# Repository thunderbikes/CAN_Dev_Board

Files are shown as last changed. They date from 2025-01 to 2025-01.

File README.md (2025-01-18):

# Alex CANBus DevBoard

## Repo:

https://github.com/alexm35644/CANBus_Devkit

## PCB:

[https://kicanvas.org/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](https://kicanvas.org/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)

# Summary

This project was made to develop CANBus for UBC ThunderBikes. It features 2 STM32 chips and 2 MCP2562FD CAN transceivers. 

# Firmware

## CAN_Firmware_Left

This firmware is for the chip on the left (near the USB Connector) and it acts as the “Master”. It sends CAN frames.

## CAN_firmware_Right

This firmware is meant for the chip on the right. It acts as the “Slave”. It receives the CAN frame and prints it via UART.

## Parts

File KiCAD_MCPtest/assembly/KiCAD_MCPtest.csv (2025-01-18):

Reference | Value | Footprint | Qty | LCSC Part #
C1,C14 | 4u7 | Capacitor_SMD:C_0603_1608Metric | 2 | C19666
C2,C3,C4,C5,C6,C15,C16,C17,C18,C19,C24,C25,C26,C27 | 100n | Capacitor_SMD:C_0402_1005Metric | 14 | C1525
C7,C20 | 1u | Capacitor_SMD:C_0402_1005Metric | 2 | C52923
C8,C10,C21,C23 | 12p | Capacitor_SMD:C_0402_1005Metric | 4 | C1547
C9,C22 | 10n | Capacitor_SMD:C_0402_1005Metric | 2 | C15195
C11,C12 | 10u | Capacitor_SMD:C_1206_3216Metric | 2 | C13585
C13 | 10nF | Capacitor_SMD:C_0603_1608Metric | 1 | C57112
D1,D4 | BLUE | LED_SMD:LED_0603_1608Metric | 2 | C72041
D2 | B5819W | Diode_SMD:D_SOD-123 | 1 | C916074
D3 | RED | LED_SMD:LED_0603_1608Metric | 1 | C2286
F1 | 500mA | Fuse:Fuse_0603_1608Metric | 1 | C210357
J7 | USB_C | Connector:USB_C_HRO_TYPE-C-31-M-12 | 1 | C165948
L1,L3 | 39n | Inductor_SMD:L_0402_1005Metric | 2 | C395063
L2 | 10uH | Inductor_SMD:L_Chilisin_BMRx00060630 | 1 | C128692
R1,R16,R17,R22 | 10k | Resistor_SMD:R_0402_1005Metric | 4 | C25744
R3,R11 | 120 | Resistor_SMD:R_0402_1005Metric | 2 | C2909315
R4,R8 | 2k2 | Resistor_SMD:R_0402_1005Metric | 2 | C25879
R5 | 100k | Resistor_SMD:R_0603_1608Metric | 1 | C25803
R6 | 68k | Resistor_SMD:R_0603_1608Metric | 1 | C23231
R7,R18 | 1k5 | Resistor_SMD:R_0603_1608Metric | 2 | C22843
R9,R19 | 47 | Resistor_SMD:R_0402_1005Metric | 2 | C25118
R12 | 47k | Resistor_SMD:R_0603_1608Metric | 1 | C25819
R13 | 15k | Resistor_SMD:R_0603_1608Metric | 1 | C22809
R14 | 270 | Resistor_SMD:R_0603_1608Metric | 1 | C22966
R15 | 1k | Resistor_SMD:R_0603_1608Metric | 1 | C21190
R20,R21 | 5.1k | Resistor_SMD:R_0402_1005Metric | 2 | C25905
SW1 | SW_Push | Button_Switch_SMD:Button_TL3342 | 1 | C115351
U1,U5 | STM32F103C8Tx | Package_QFP:LQFP-48_7x7mm_P0.5mm | 2 | C8734
U2,U4 | MCP2562-E-SN | Package_SO:SOIC-8_3.9x4.9mm_P1.27mm | 2 | C124016
U3 | MP2359DJ-LF-Z | Package_TO_SOT_SMD:SOT-23-6 | 1 | C18198375
U6 | USBLC6-2SC6 | Package_TO_SOT_SMD:SOT-23-6 | 1 | C7519
Y1,Y2 | 16MHz | Crystal:Crystal_SMD_3225-4Pin_3.2x2.5mm | 2 | C13738

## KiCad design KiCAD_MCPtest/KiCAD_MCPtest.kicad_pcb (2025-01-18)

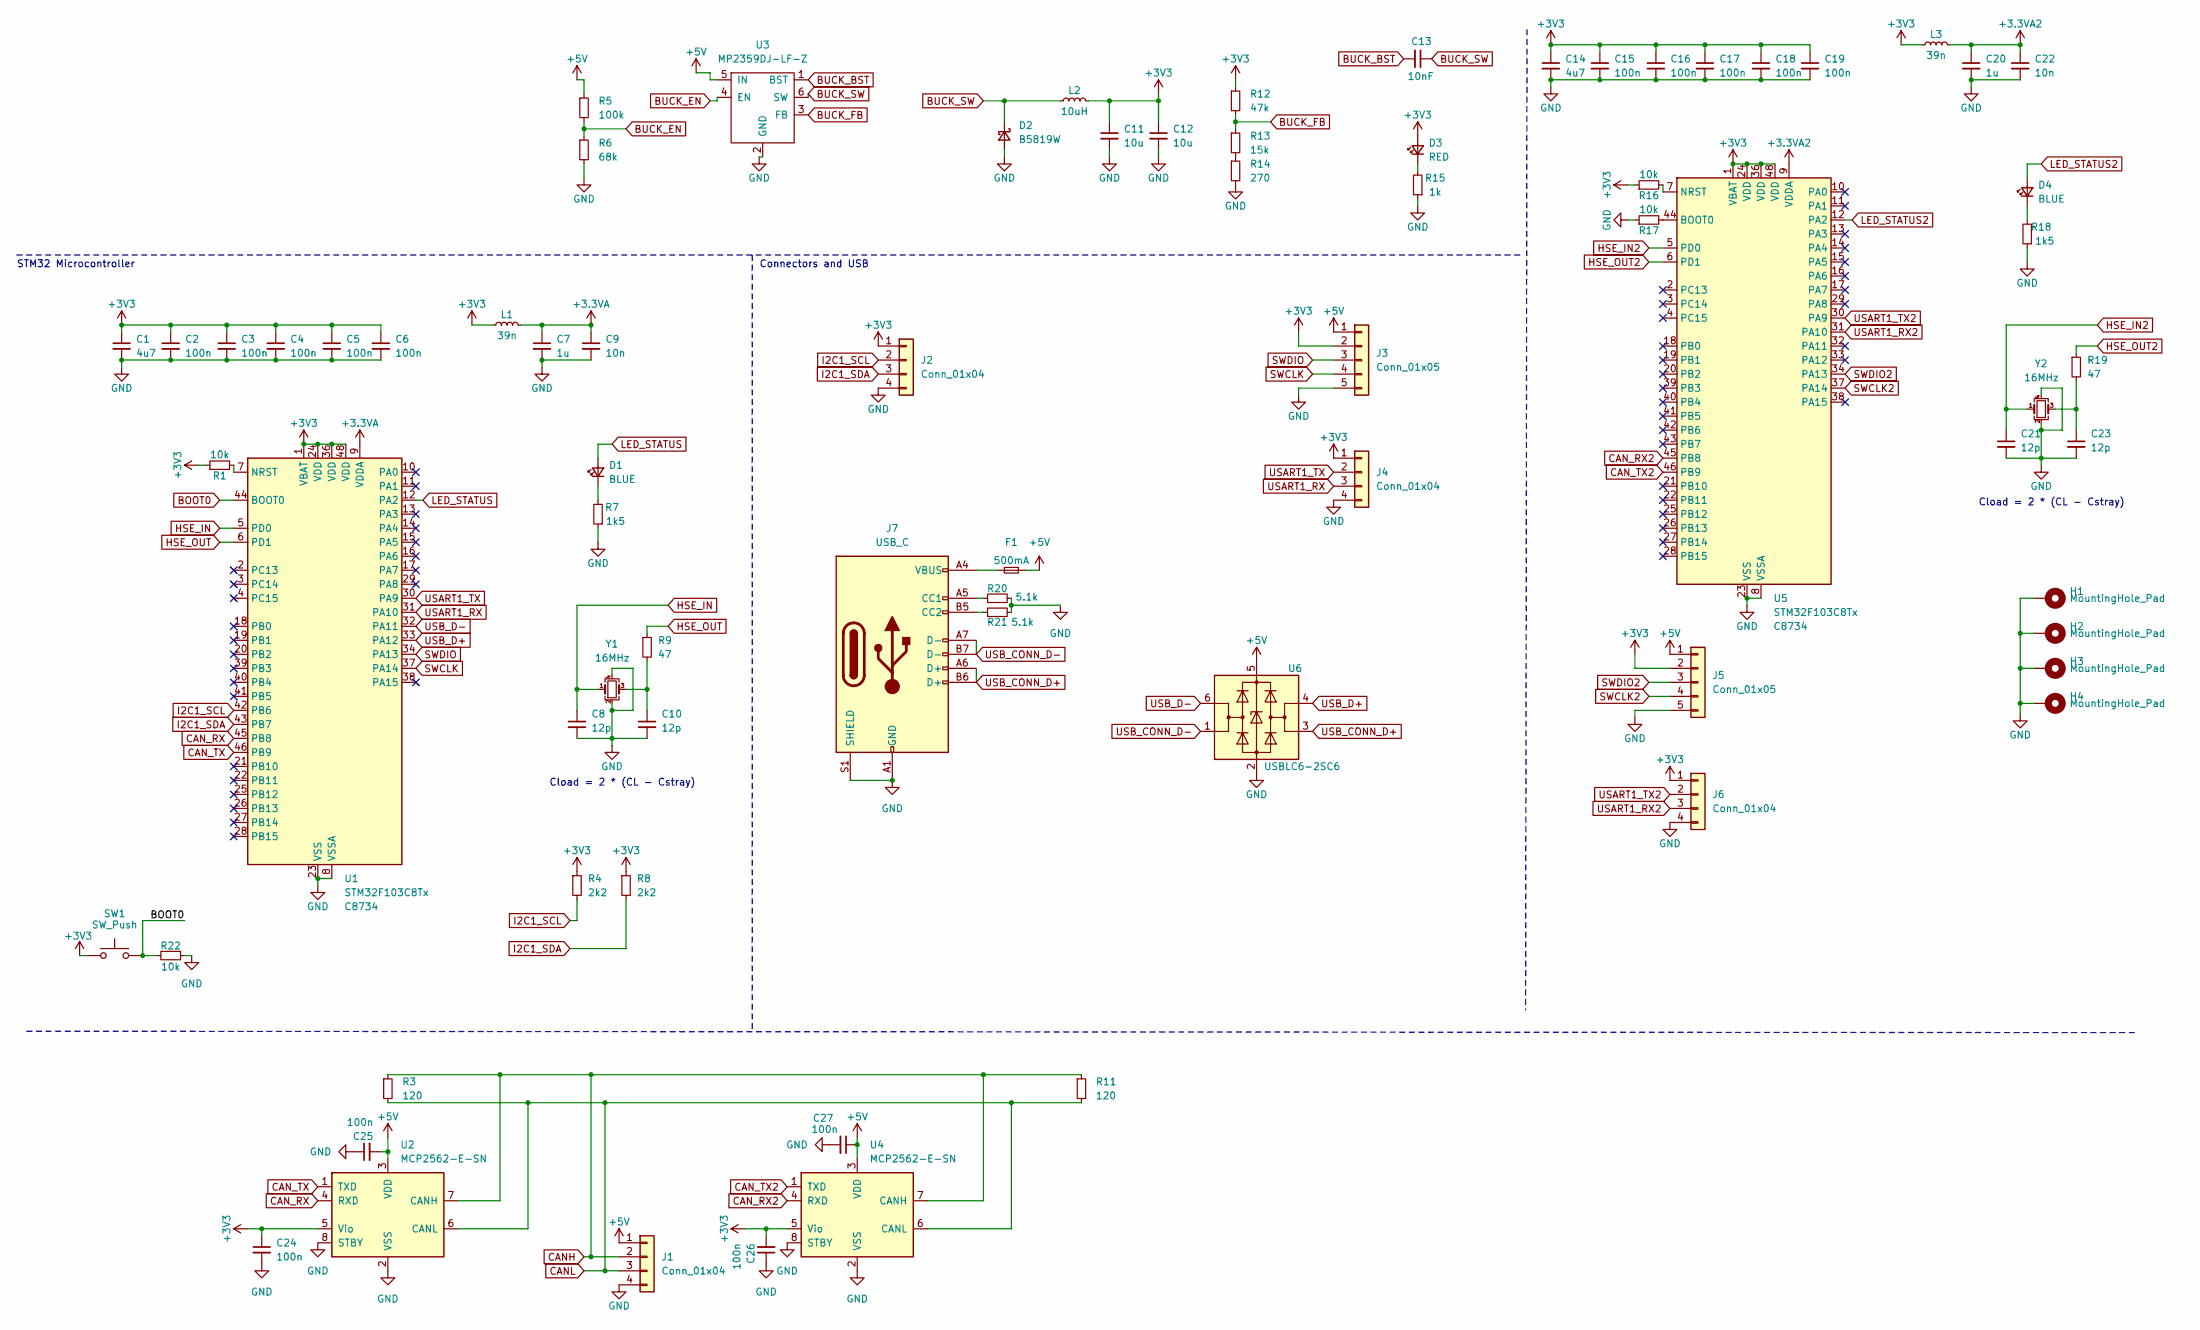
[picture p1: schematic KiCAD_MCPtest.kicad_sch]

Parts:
C1, C14: 4u7; C_0603_1608Metric; LCSC Part # C19666
C2, C3, C4, C5, C6, C15, C16, C17, C18, C19, C24, C25, C26, C27: 100n; C_0402_1005Metric; LCSC Part # C1525
C7, C20: 1u; C_0402_1005Metric; LCSC Part # C52923
C8, C10, C21, C23: 12p; C_0402_1005Metric; LCSC Part # C1547
C9, C22: 10n; C_0402_1005Metric; LCSC Part # C15195
C11, C12: 10u; C_1206_3216Metric; LCSC Part # C13585
C13: 10nF; C_0603_1608Metric; LCSC Part # C57112
D1, D4: BLUE; LED_0603_1608Metric; LCSC Part # C2286
D2: B5819W; D_SOD-123; LCSC Part # C64885
D3: RED; LED_0603_1608Metric; LCSC Part # C2286
F1: 500mA; Fuse_0603_1608Metric; LCSC Part # C210357
H1, H2, H3, H4: MountingHole_Pad; MountingHole_4.3mm_M4_Pad_Via
J1, J2, J4, J6: Conn_01x04; PinHeader_1x04_P2.54mm_Vertical
J3, J5: Conn_01x05; PinHeader_1x05_P2.54mm_Vertical
J7: USB_C; USB_C_HRO_TYPE-C-31-M-12; LCSC Part # C165948
L1, L3: 39n; L_0402_1005Metric; LCSC Part # C395063
L2: 10uH; L_Chilisin_BMRx00060630; LCSC Part # C128692
R1, R16, R17, R22: 10k; R_0402_1005Metric; LCSC Part # C25744
R3, R11: 120; R_0402_1005Metric; LCSC Part # C2909315
R4, R8: 2k2; R_0402_1005Metric; LCSC Part # C25879
R5: 100k; R_0603_1608Metric; LCSC Part # C25803
R6: 68k; R_0603_1608Metric; LCSC Part # C23231
R7, R18: 1k5; R_0603_1608Metric; LCSC Part # C22843
R9, R19: 47; R_0402_1005Metric; LCSC Part # C25118
R12: 47k; R_0603_1608Metric; LCSC Part # C25819
R13: 15k; R_0603_1608Metric; LCSC Part # C22809
R14: 270; R_0603_1608Metric; LCSC Part # C22966
R15: 1k; R_0603_1608Metric; LCSC Part # C21190
R20, R21: 5.1k; R_0402_1005Metric; LCSC Part # C25905
SW1: SW_Push; Button_TL3342; LCSC Part # C115351
U1, U5: STM32F103C8Tx; LQFP-48_7x7mm_P0.5mm; LCSC Part # C8734
U2, U4: MCP2562-E-SN; SOIC-8_3.9x4.9mm_P1.27mm; LCSC Part # C124016
U3: MP2359DJ-LF-Z; SOT-23-6; LCSC Part # C18198375
U6: USBLC6-2SC6; SOT-23-6; LCSC Part # C7519
Y1, Y2: 16MHz; Crystal_SMD_3225-4Pin_3.2x2.5mm; LCSC Part # C13738

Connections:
+3.3VA: C7.1, C9.1, L1.2, U1.9 (VDDA)
+3.3VA2: C20.1, C22.1, L3.2, U5.9 (VDDA)
+3V3: C1.1, C2.1, C3.1, C4.1, C5.1, C6.1, C11.1, C12.1, C14.1, C15.1, C16.1, C17.1, C18.1, C19.1, C24.1, C26.2, D3.2 (A), J2.1, J3.2, J4.1, J5.2, J6.1, L1.1, L2.2, L3.1, R1.1, R4.1, R8.1, R12.1, R16.1, SW1.1, U1.1 (VBAT), U1.24 (VDD), U1.36 (VDD), U1.48 (VDD), U2.5 (Vio), U4.5 (Vio), U5.1 (VBAT), U5.24 (VDD), U5.36 (VDD), U5.48 (VDD)
+5V: C25.2, C27.1, F1.2, J1.1, J3.1, J5.1, R5.1, U2.3 (VDD), U3.5 (IN), U4.3 (VDD), U6.5 (VBUS)
BOOT0: R22.2, SW1.2, U1.44 (BOOT0)
BUCK_BST: C13.2, U3.1 (BST)
BUCK_EN: R5.2, R6.1, U3.4 (EN)
BUCK_FB: R12.2, R13.1, U3.3 (FB)
BUCK_SW: C13.1, D2.1 (K), L2.1, U3.6 (SW)
CANH: J1.2, R3.1, R11.1, U2.7 (CANH), U4.7 (CANH)
CANL: J1.3, R3.2, R11.2, U2.6 (CANL), U4.6 (CANL)
CAN_RX: U1.45 (PB8), U2.4 (RXD)
CAN_RX2: U4.4 (RXD), U5.45 (PB8)
CAN_TX: U1.46 (PB9), U2.1 (TXD)
CAN_TX2: U4.1 (TXD), U5.46 (PB9)
GND: C1.2, C2.2, C3.2, C4.2, C5.2, C6.2, C7.2, C8.2, C9.2, C10.2, C11.2, C12.2, C14.2, C15.2, C16.2, C17.2, C18.2, C19.2, C20.2, C21.2, C22.2, C23.2, C24.2, C25.1, C26.1, C27.2, D2.2 (A), H1.1, H2.1, H3.1, H4.1, J1.4, J2.4, J3.5, J4.4, J5.5, J6.4, J7.A1 (GND), J7.A12 (GND), J7.B1 (GND), J7.B12 (GND), J7.S1 (SHIELD), R6.2, R7.1, R14.2, R15.1, R17.1, R18.1, R20.2, R21.2, R22.1, U1.8 (VSSA), U1.23 (VSS), U1.35 (VSS), U1.47 (VSS), U2.2 (VSS), U2.8 (STBY), U3.2 (GND), U4.2 (VSS), U4.8 (STBY), U5.8 (VSSA), U5.23 (VSS), U5.35 (VSS), U5.47 (VSS), U6.2 (GND), Y1.2, Y1.4, Y2.2, Y2.4
HSE_IN: C8.1, U1.5 (PD0), Y1.1
HSE_IN2: C21.1, U5.5 (PD0), Y2.1
HSE_OUT: R9.1, U1.6 (PD1)
HSE_OUT2: R19.1, U5.6 (PD1)
I2C1_SCL: J2.2, R4.2, U1.42 (PB6)
I2C1_SDA: J2.3, R8.2, U1.43 (PB7)
LED_STATUS: D1.2 (A), U1.12 (PA2)
LED_STATUS2: D4.2 (A), U5.12 (PA2)
unnamed: C10.1, R9.2, Y1.3
unnamed: C23.1, R19.2, Y2.3
unnamed: D1.1 (K), R7.2
unnamed: D3.1 (K), R15.2
unnamed: D4.1 (K), R18.2
unnamed: F1.1, J7.A4 (VBUS), J7.A9 (VBUS), J7.B4 (VBUS), J7.B9 (VBUS)
unnamed: J7.A5 (CC1), R20.1
unnamed: J7.B5 (CC2), R21.1
unnamed: R13.2, R14.1
unnamed: R1.2, U1.7 (NRST)
unnamed: R17.2, U5.44 (BOOT0)
unnamed: R16.2, U5.7 (NRST)
SWCLK: J3.4, U1.37 (PA14)
SWCLK2: J5.4, U5.37 (PA14)
SWDIO: J3.3, U1.34 (PA13)
SWDIO2: J5.3, U5.34 (PA13)
USART1_RX: J4.3, U1.31 (PA10)
USART1_RX2: J6.3, U5.31 (PA10)
USART1_TX: J4.2, U1.30 (PA9)
USART1_TX2: J6.2, U5.30 (PA9)
USB_CONN_D+: J7.A6 (D+), J7.B6 (D+), U6.3 (I/O2)
USB_CONN_D-: J7.A7 (D-), J7.B7 (D-), U6.1 (I/O1)
USB_D+: U1.33 (PA12), U6.4 (I/O2)
USB_D-: U1.32 (PA11), U6.6 (I/O1)

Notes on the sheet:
Cload = 2 * (CL - Cstray)
STM32 Microcontroller
Connectors and USB

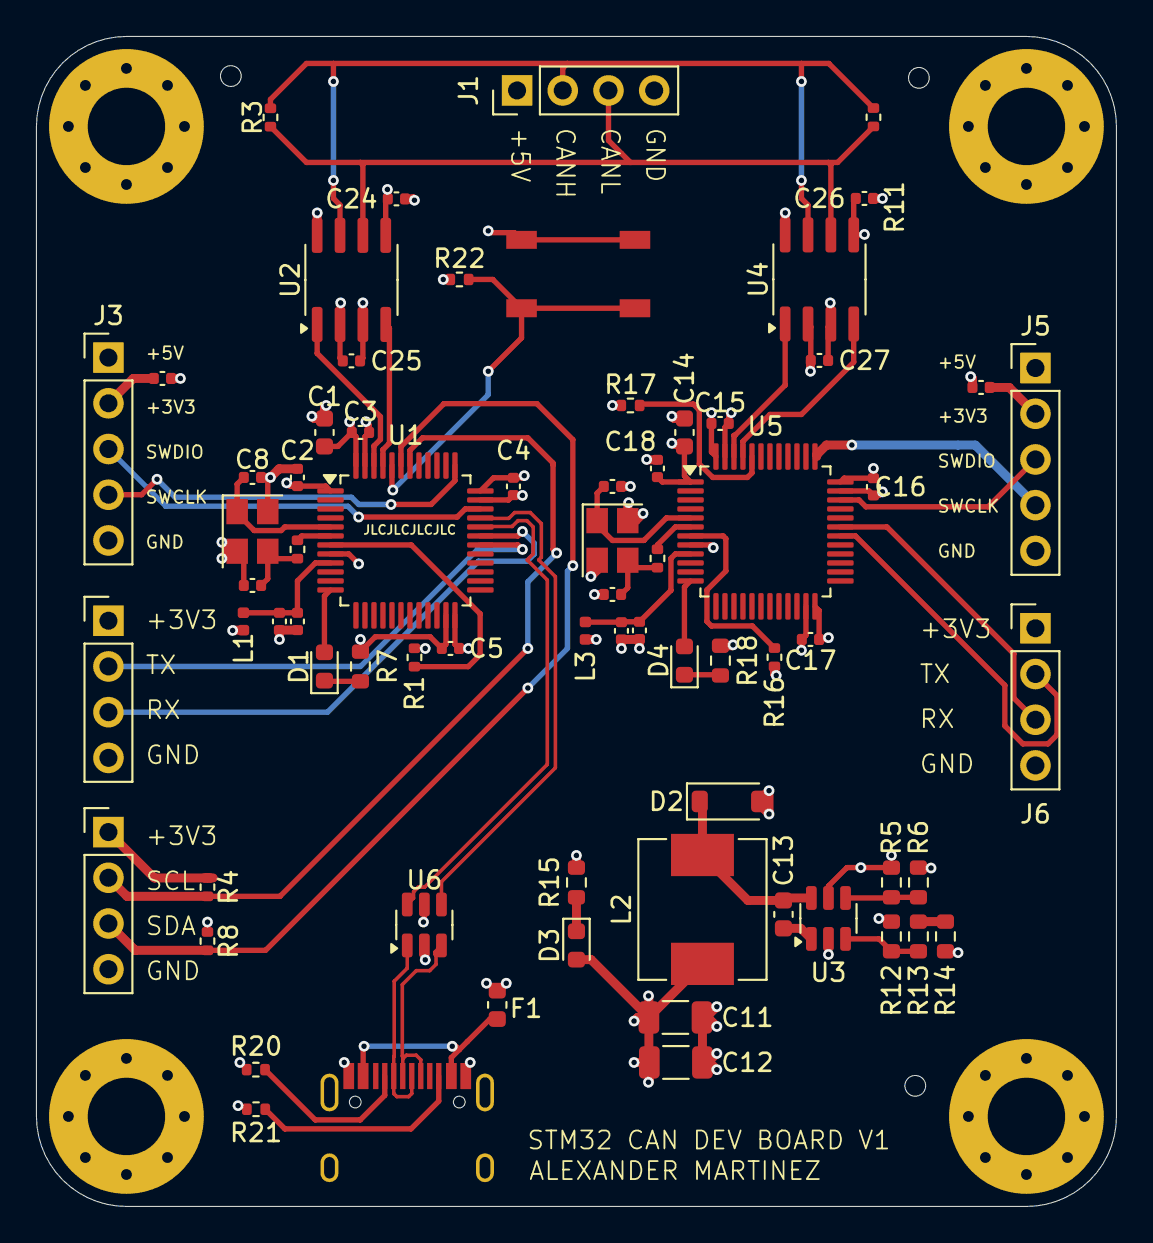
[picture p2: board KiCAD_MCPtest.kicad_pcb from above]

Board: 4 copper layers, 60.0 x 65.0 mm, 75 parts (0 on the bottom side), 48 nets.

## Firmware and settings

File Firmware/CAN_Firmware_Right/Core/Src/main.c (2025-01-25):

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
/* Includes ------------------------------------------------------------------*/
#include "main.h"
#include "can.h"
#include "i2c.h"
#include "usart.h"
#include "usb.h"
#include "gpio.h"


/* USER CODE BEGIN PV */



CAN_TxHeaderTypeDef   TxHeader;
CAN_RxHeaderTypeDef   RxHeader; //CAN Bus Transmit Header
uint8_t               TxData[8];
uint32_t              TxMailbox;
CAN_FilterTypeDef canfil; //CAN Bus Filter
uint32_t canMailbox; //CAN Bus Mail box variable

uint8_t canRX[8] = {0x0,0x0,0x0,0x0,0x0,0x0,0x0,0x0};  //CAN Bus Receive Buffer

const char *error_messages[16] = {
    "ERR0: Identification error.",
    "ERR1: Over voltage.",
    "ERR2: Low voltage.",
    "ERR3: Reserved.",
    "ERR4: Stall.",
    "ERR5: Internal volts fault.",
    "ERR6: Over temperature.",
    "ERR7: Throttle error at power-up.",
    "ERR8: Reserved.",
    "ERR9: Internal reset.",
    "ERR10: Hall throttle open or short-circuit.",
    "ERR11: Angle sensor error.",
    "ERR12: Reserved.",
    "ERR13: Reserved.",
    "ERR14: Motor over-temperature.",
    "ERR15: Hall galvanometer sensor error."
};



/* USER CODE END PV */

void SystemClock_Config(void);
/* USER CODE BEGIN PFP */
#define PUTCHAR_PROTOTYPE int __io_putchar(int ch)

/* USER CODE END PFP */

/**
  * @brief  The application entry point.
  * @retval int
  */
int main(void)
{

  /* MCU Configuration--------------------------------------------------------*/

  /* Reset of all peripherals, Initializes the Flash interface and the Systick. */
  HAL_Init();

  /* Configure the system clock */
  SystemClock_Config();

  /* Initialize all configured peripherals */
  MX_GPIO_Init();
  MX_CAN_Init();
  MX_I2C1_Init();
  MX_USART1_UART_Init();
  MX_USB_PCD_Init();
  /* USER CODE BEGIN 2 */

  CAN_FilterTypeDef canfilterconfig;


  canfil.FilterBank = 0;
  canfil.FilterMode = CAN_FILTERMODE_IDMASK;
  canfil.FilterFIFOAssignment = CAN_RX_FIFO0;
  canfil.FilterIdHigh = 0;
  canfil.FilterIdLow = 0;
  canfil.FilterMaskIdHigh = 0;
  canfil.FilterMaskIdLow = 0;
  canfil.FilterScale = CAN_FILTERSCALE_32BIT;
  canfil.FilterActivation = ENABLE;
  canfil.SlaveStartFilterBank = 14;

  TxHeader.IDE = CAN_ID_STD;
  TxHeader.StdId = 0x446;
  TxHeader.RTR = CAN_RTR_DATA;
  TxHeader.DLC = 8;

  TxData[0] = 0x01;  
  TxData[1] = 0x02; 
  TxData[2] = 0x03; 
  TxData[3] = 0x04; 
  TxData[4] = 0x05; 
  TxData[5] = 0x06; 
  TxData[6] = 0x07; 
  TxData[7] = 0x08; 




/**
  * @brief Print CANBUS Error messages 
  * @author Dean
  * @retval None
  */

   


  HAL_CAN_ConfigFilter(&hcan,&canfil);
  HAL_CAN_Start(&hcan);
  HAL_CAN_ActivateNotification(&hcan,CAN_IT_RX_FIFO0_MSG_PENDING);

  if (HAL_CAN_ActivateNotification(&hcan, CAN_IT_RX_FIFO0_MSG_PENDING) != HAL_OK)
  {
	  Error_Handler();
  }

  /* USER CODE END 2 */

  /* Infinite loop */
  /* USER CODE BEGIN WHILE */
  while (1)
  {
    

    /* USER CODE END WHILE */

    /* USER CODE BEGIN 3 */
  }
  /* USER CODE END 3 */
}

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
/* USER CODE BEGIN 4 */
PUTCHAR_PROTOTYPE
{
  /* Place your implementation of fputc here */
  /* e.g. write a character to the USART1 and Loop until the end of transmission */
  HAL_UART_Transmit(&huart1, (uint8_t *)&ch, 1, 0xFFFF);

  return ch;
}

void send_uart_message(char *message) {
    HAL_UART_Transmit(&huart1, (uint8_t *)message, strlen(message), HAL_MAX_DELAY);
}



/**
  * @brief Print CANBUS Error messages 
  * @author Dean
  * @retval None
  */
void HAL_CAN_RxFifo0MsgPendingCallback(CAN_HandleTypeDef *hcan1)
{
    if (HAL_CAN_GetRxMessage(hcan1, CAN_RX_FIFO0, &RxHeader, canRX) != HAL_OK)
    {
        printf("CAN Message Read Failed. HAL ERROR... \r\n");
        return;
    }
    else
    {
        HAL_GPIO_TogglePin(USER_LED_GPIO_Port, USER_LED_Pin);
        if (RxHeader.IDE == CAN_ID_STD)
        {
            printf("Message has standard ID type...\r\n");
            printf("Message ID:\t%#lx\r\n", RxHeader.StdId);

            if(RxHeader.StdId == 0x6B0){ // BMS
              uint16_t pack_current     = (canRX[1] << 8) | canRX[0];
              uint16_t pack_voltage     = (canRX[3] << 8) | canRX[2];
              uint8_t pack_soc          = canRX[4];
              uint8_t pack_relay_state  = canRX[5];

              printf("Pack Current: %d\r\n", pack_current);
              printf("Pack Voltage: %d\r\n", pack_voltage);
              printf("Pack SoC: %d\r\n", pack_soc);
              printf("Pack Relay Status: %d\r\n", pack_relay_state);

            }
            else if(RxHeader.StdId == 0x6B1){ // BMS
              uint32_t pack_DCL = (canRX[3]<<24) | (canRX[2]<<16) | (canRX[1]<<8) | canRX[0];
              uint8_t high_temp_derating = canRX[4];
              uint8_t low_temp_derating   = canRX[5];

              printf("Pack DCL: %d\r\n", pack_DCL);
              printf("High Temp Derating: %d\r\n", high_temp_derating);
              printf("low_temp_derating: %d\r\n", low_temp_derating);
            }
            else
            {
            printf("ERROR: Unknown IDE type\r\n");
            return;
            }
        }
        else if (RxHeader.IDE == CAN_ID_EXT)
        {
            printf("Message has extended ID type...\r\n");
            printf("Message ID:\t%#lx\r\n", RxHeader.ExtId);

            if (RxHeader.ExtId == 0x0CF11E05)
            {
                uint16_t RPM = (canRX[1] << 8) | canRX[0];
                uint16_t Current = (canRX[3] << 8) | canRX[2];
                uint16_t Voltage = (canRX[5] << 8) | canRX[4];

                printf("R  P  M = %u rpm\r\n", RPM);
                printf("Current = %u A\r\n", Current/ 10);
                printf("Voltage = %u V\r\n", Voltage / 10);

                for (uint8_t i = 0; i < 16; i++)
                {
                    if (((canRX[7] << 8) | canRX[6]) & (1 << i))
                    {
                        printf("%s\r\n", error_messages[i]);
                    }
                }
            }
          
            else if (RxHeader.ExtId == 0x0CF11F05)
            {
                
                uint8_t throttle_signal = canRX[0];
                int8_t controller_temp = canRX[1] - 40; 
                int8_t motor_temp = canRX[2] - 30; 
                printf("Throttle Signal: %d V\r\n", throttle_signal);
                printf("Controller Temperature: %d ℃\r\n", controller_temp);
                printf("Motor Temperature: %d ℃\r\n", motor_temp);

               
                if (canRX[4] & 0x01)
                    printf("Controller Command: Forward\r\n");
                else if (canRX[4] & 0x02)
                    printf("Controller Command: Backward\r\n");
                else if (canRX[4] & 0x03)
                    printf("Controller Command: Reserved\r\n");
                else printf("Controller Command: Neutral\r\n");

                if (((canRX[4] >> 2) & 0x03 )== 0x00)
                    printf("Feedback: Stationary\r\n");
                else if (((canRX[4] >> 2) & 0x03 ) == 0x01)
                    printf("Feedback: Forward\r\n");
                else if (((canRX[4] >> 2) & 0x03 ) == 0x02)
                    printf("Feedback: Backward\r\n");
                else
                    printf("Feedback: Reserved\r\n");

                printf("Switch Status:\r\n");
                printf("  Boost: %s\r\n", (canRX[5] & 0x80) ? "ON" : "OFF");
                printf("  Foot Switch: %s\r\n", (canRX[5] & 0x40) ? "ON" : "OFF");
                printf("  Forward Switch: %s\r\n", (canRX[5] & 0x20) ? "ON" : "OFF");
                printf("  Backward Switch: %s\r\n", (canRX[5] & 0x10) ? "ON" : "OFF");
                printf("  12V Brake Switch: %s\r\n", (canRX[5] & 0x08) ? "ON" : "OFF");
                printf("  Hall C: %s\r\n", (canRX[5] & 0x04) ? "ON" : "OFF");
                printf("  Hall B: %s\r\n", (canRX[5] & 0x02) ? "ON" : "OFF");
                printf("  Hall A: %s\r\n", (canRX[5] & 0x01) ? "ON" : "OFF");
            }
        }
        else
        {
            printf("ERROR: Unknown IDE type\r\n");
            return;
        }

    
        printf("Message length is %ld byte(s)\r\n", RxHeader.DLC);
        for (uint8_t i = 0; i < 8; i++)
        {
            printf("Byte %d: 0x%02X\r\n", i, canRX[i]);
        }
    }
}


/* USER CODE END 4 */
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


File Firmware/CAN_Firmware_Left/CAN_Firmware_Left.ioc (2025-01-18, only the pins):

Mcu.UserName=STM32F103C8Tx
PA10.Signal=USART1_RX
PA11.Signal=USB_DM
PA12.Signal=USB_DP
PA13.Signal=SYS_JTMS-SWDIO
PA14.Signal=SYS_JTCK-SWCLK
PA2.GPIO_Label=USER_LED
PA2.Signal=GPIO_Output
PA9.Signal=USART1_TX
PB6.Signal=I2C1_SCL
PB7.Signal=I2C1_SDA
PB8.Signal=CAN_RX
PB9.Signal=CAN_TX
PD0-OSC_IN.Signal=RCC_OSC_IN
PD1-OSC_OUT.Signal=RCC_OSC_OUT

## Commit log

2025-01-22 Update main.c
    Add Canbus erros messages
2025-01-23 Fixed LED
2025-01-25 Update main.c
    Can Error msg done
    [main.c]
2025-01-25 Motor Controller CAN test
2025-01-25 BMS messages

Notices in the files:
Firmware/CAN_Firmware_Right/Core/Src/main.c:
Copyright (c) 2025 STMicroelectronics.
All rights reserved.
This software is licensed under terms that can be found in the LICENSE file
